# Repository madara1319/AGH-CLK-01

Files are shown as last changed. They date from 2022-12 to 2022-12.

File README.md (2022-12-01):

# AGH-CLK-01

Project of embedded wristwatch module powered by li-pol cell realised for University course Design-Laboratory
## Project assumptions
The main goal is to make self-contained embedded wristwatch module that could be used with dedicated wrist as a complete wristwatch. That device will have his own supply made by li-pol cell with dedicated hardware driver. As a display will be used full color LCD screen module with 240x240px and ST7789 driver. Device will be controlled by microprocessor STM32 (particular type will be pick in time) that would be placed on a dedicated printed circuit board “AGH-CLK-01” with the rest of peripherals. Everything should be assembled as a ready-to-use device.

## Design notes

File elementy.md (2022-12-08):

# Elementy smd do zakupienia

Do ustalenia w tym tygodniu co zakupujemy  

## N-Mosfet Conteo_pro  
[N-Mosfet](https://allegro.pl/oferta/irlml2060-60v-1-2a-n-mosfet-1-25w-sot-23-e1903-7875509949) 
https://allegro.pl/oferta/tranzystor-lge2300-n-mosfet-4a-20v-sot23-x10szt-8729061588 **(MM) electroniksc**
## P-Mosfet Elektroniksc  
[P-Mosfet](https://allegro.pl/oferta/irlml6402-sot23-p-channel-si2301-kpl-10szt-12848211828)  **(MM) ok**
## Kwarc Elektoniksc 
[Rezonator kwarcowy](https://allegro.pl/oferta/kwarc-32-768khz-smd-abs07-32-768khz-t-12-5pf-x2szt-12064929900)  **(MM) ok, ale w komplecie są 2 szt, więc wystarczą 2 komplety**

Kwarc inna firma  
Wymiar czestotliwosc okej i 4 piny  
[Rezonator kwarcowy](https://allegro.pl/oferta/rezonator-kwarcowy-smd-32-768khz-ndk-1szt-a529-6692482864)  **(MM) Nie ma sensu brać z innej firmy skoro mamy tamten**
## Gniazdo usb Conteo_pro 
[Gniazdo usb b](https://allegro.pl/oferta/mx-105017-0001-gniazdo-usb-b-micro-smt-5pin-12054224486) 
https://allegro.pl/oferta/gniazdo-micro-usb-5pin-pcb-10118194-0001lf-c-x2szt-9531914757 **(MM) gniazdo z electrosc**
## Modul do ladowarki Elektroniksc
[tp4056 do ladowarki lipo](https://allegro.pl/oferta/m5137-ladowarka-akumulatorow-li-ion-to4056-8863674707) Tu od elektronicsc z allegro co mosfet jeden wczesniej link ale trzeba by odlutowywac   
[tp4056 do ladowarki lipo](https://allegro.pl/oferta/tp4054-42-kontroler-ladowania-li-lon-sot23-5-7953080285) Tez od Elektroniksc ale to tp4054 i byloby bez odlutowywania  **(MM) Bardzo dobry pomysł**

## Stabilizator napiecia Conteo_pro
[stabilizator napięcia](https://allegro.pl/oferta/spx5205m5l3-3tr-stabilizator-napiecia-ldo-3-3v-12409161294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) **(MM) ok**
https://allegro.pl/oferta/stabilizator-ap2121n-3-3-ef8-sot23-3-3-3v-x4szt-9440621435 **(MM) jednak lepiej ten**

## Bufor inna firma
[Bufor](https://allegro.pl/oferta/sn74auc2g34dbvr-x4szt-12473535404) Bufor inny niz SN74AUC2G34DBVR ale podobny do 74AUC2G34 tylko nie jest ani od elektronicsc ani conteo_pro  
[Bufor](https://allegro.pl/oferta/nc7wz16p6x-smd-s-c-88-dual-buffer-9958671515)Inny bufor ale dual Buffer na CMOS [karta katalogowa](https://www.mouser.com/datasheet/2/308/NC7WZ16-1301496.pdf)  
[Bufor ale jakis inny ale od elektroniksc](https://allegro.pl/oferta/74lvc1g125gw-bufor-tssop5-x5szt-12080132627) nie wiem czy taki by byl bo nie dual buffer [karta katalogowa](https://www.mouser.pl/datasheet/2/916/74LVC1G125-1512149.pdf)  **(MM) ten będzie najtańszy**

[Bufor ale tez inny ale od conteo_pro](https://allegro.pl/oferta/m74vhc1gt125df2g-cyfrowy-3-stanowy-bufor-sc88a-11849828081) tez moze nie pasowac 3stanowy [karta katalogowa](https://www.mouser.com/datasheet/2/308/MC74VHC1GT125-D-78788.pdf)  
## Przycisk Elektroniksc
[Przycisk](https://allegro.pl/oferta/int1188f15a-mikroprzycisk-3-1x3-1-1-5mm-smd-7300457422)
Przycisk inny ale moze by był?  **(MM) hmm... powinien być raczej boczny a nie z góry Conteno ma w ofercie taki: https://allegro.pl/oferta/kss341glfs-mikroprzelacznik-tact-spst-no-smt-11768921473**  
**A tu jest nawet lepszy, bo w komplecie 10 sztuk https://allegro.pl/oferta/mikroprzycisk-4-7x1-9mm-3-5mm-smd-off-on-x10szt-10724789402**

## STM32 inna firma
[Zakladany stm32](https://allegrolokalnie.pl/oferta/mikrokontroler-stm32l051k6t6)  **(MM) Przy smarcie zakup 3 procków wystarczy, żeby mieć darmową dostawę, więc to jak najbardziej może być zakupione u kogoś innego**

[stm32 inny](https://allegro.pl/oferta/stm32g031j6m6-mikrokontroler-arm-32kb-64mhz-sop-8-11824556072) inny stm32 ale od Conteo_pro **(MM) Zdecydowanie zbyt mało pinów xD**

## Connector_wire_soldier_wire  
Tu do konca nie wiem jaki to drut ma byc  **(MM) aaa... rzeczywiście element THT. Chodziło mi tutaj o NTC 10k do kontroli temperatury baterii https://allegro.pl/oferta/termistor-ntc110-10k-1-3435k-pomiarowy-x5szt-12795393180 natomiast jeśli zdecydujemy się na ten alternatywny kontroler ładowania baterii to tam nie ma pomiaru temperatury i wtedy NTC też nie potrzebujemy**

## Cena za stmy
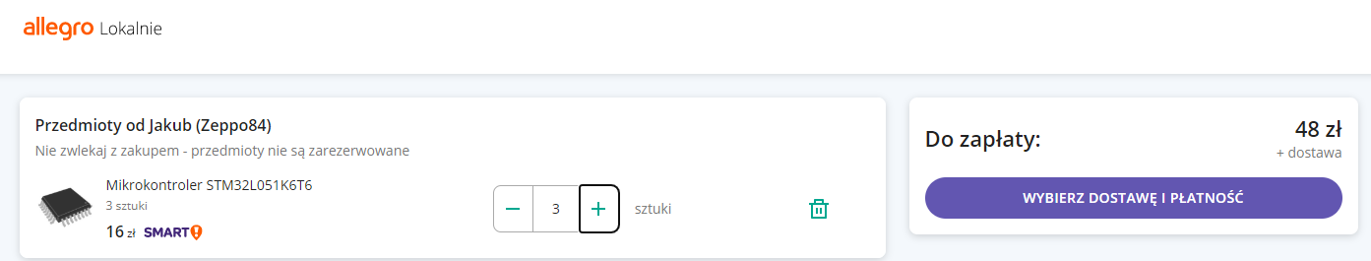
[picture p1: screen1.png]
Cena za stmy

## Cena za pozostale elementy
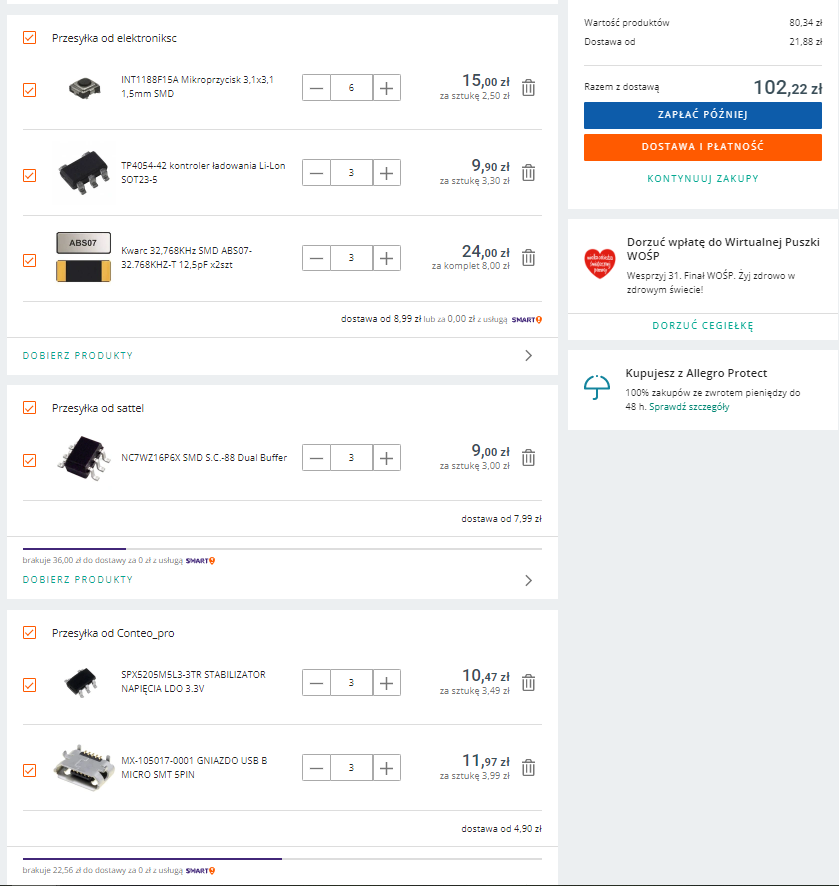
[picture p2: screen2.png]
Cena za pozostale elementy


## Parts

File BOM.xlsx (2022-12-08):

Ref | Qnty | Value | Cmp name | Footprint | Description
C1, C2, C3, | 3 | 100n | C | Capacitor_SMD:C_0603_1608Metric_Pad1.08x0.95mm_HandSolder | Unpolarized capacitor
C4, | 1 | 20pF | C | Capacitor_SMD:C_0603_1608Metric_Pad1.08x0.95mm_HandSolder | Unpolarized capacitor
C5, | 1 | 27pF | C | Capacitor_SMD:C_0603_1608Metric_Pad1.08x0.95mm_HandSolder | Unpolarized capacitor
C6, C7, C8, | 3 | 1u | C | Capacitor_SMD:C_0805_2012Metric_Pad1.18x1.45mm_HandSolder | Unpolarized capacitor
C9, C11, | 2 | 10uF | C | Capacitor_SMD:C_1206_3216Metric_Pad1.33x1.80mm_HandSolder | Unpolarized capacitor
C10, C12, | 2 | 100nF | C | Capacitor_SMD:C_0603_1608Metric_Pad1.08x0.95mm_HandSolder | Unpolarized capacitor
D1, D2, | 2 | BAT54S | BAT54S | Package_TO_SOT_SMD:SOT-23 | schottky barrier diode
J1, | 1 | Conn_01x06_Male | Conn_01x06_Male | Connector_PinHeader_2.54mm:PinHeader_1x06_P2.54mm_Vertical | Generic connector, single row, 01x06, script generated (kicad-library-utils/schlib/autogen/connector/)
J2, | 1 | USB_B_Micro | USB_B_Micro | Connector_USB:USB_Micro-B_Amphenol_10104110_Horizontal | USB Micro Type B connector
J3, | 1 | Conn_01x03_Male | Conn_01x03_Male | Connector_PinHeader_2.54mm:PinHeader_1x03_P2.54mm_Vertical | Generic connector, single row, 01x03, script generated (kicad-library-utils/schlib/autogen/connector/)
J4, | 1 | Conn_01x12 | Conn_01x12 | Connector:Flex_Tape_12x0.635 | Generic connector, single row, 01x12, script generated (kicad-library-utils/schlib/autogen/connector/)
J5, | 1 | Conn_01x02_Male | Conn_01x02_Male | Connector_PinHeader_2.54mm:PinHeader_1x02_P2.54mm_Vertical | Generic connector, single row, 01x02, script generated (kicad-library-utils/schlib/autogen/connector/)
NTC1, | 1 | R | R | Connector_Wire:SolderWire-0.5sqmm_1x02_P4.6mm_D0.9mm_OD2.1mm | Resistor
Q1, | 1 | IRLML2060 | IRLML2060 | Package_TO_SOT_SMD:SOT-23 | 1.2A Id, 60V Vds, 480mOhm Rds, N-Channel HEXFET Power MOSFET, SOT-23
Q2, | 1 | IRLML6402 | IRLML6402 | Package_TO_SOT_SMD:SOT-23 | -3.7A Id, -20V Vds, 65mOhm Rds, P-Channel HEXFET Power MOSFET, SOT-23
Q3, | 1 | BC817 | BC817 | Package_TO_SOT_SMD:SOT-23 | 0.8A Ic, 45V Vce, NPN Transistor, SOT-23
R1, R3, R4, | 3 | 100R | R | Resistor_SMD:R_0603_1608Metric_Pad0.98x0.95mm_HandSolder | Resistor
R2, R6, | 2 | 100k | R | Resistor_SMD:R_0603_1608Metric_Pad0.98x0.95mm_HandSolder | Resistor
R5, R7, R9, R14, R15, | 5 | 10k | R | Resistor_SMD:R_0603_1608Metric_Pad0.98x0.95mm_HandSolder | Resistor
R8, | 1 | 1k | R | Resistor_SMD:R_0603_1608Metric_Pad0.98x0.95mm_HandSolder | Resistor
R10, | 1 | 10R | R | Resistor_SMD:R_0603_1608Metric_Pad0.98x0.95mm_HandSolder | Resistor
R11, R12, | 2 | R | R | Resistor_SMD:R_0603_1608Metric_Pad0.98x0.95mm_HandSolder | Resistor
R13, | 1 | 2,4k | R | Resistor_SMD:R_0603_1608Metric_Pad0.98x0.95mm_HandSolder | Resistor
SW1, SW2, | 2 | SW_Push | SW_Push | Button_Switch_SMD:SW_SPST_B3U-3000P-B | Push button switch, generic, two pins
U1, | 1 | STM32L051K6Tx | STM32L051K6Tx | Package_QFP:LQFP-32_7x7mm_P0.8mm | ARM Cortex-M0+ MCU, 32KB flash, 8KB RAM, 32MHz, 1.65-3.6V, 25 GPIO, LQFP-32
U2, | 1 | MIC5353-3.3YMT | MIC5353-3.3YMT | Package_DFN_QFN:MLF-6-1EP_1.6x1.6mm_P0.5mm_EP0.5x1.26mm | High-performance, single-output, ultra-low LDO regulator
U3, | 1 | 74AUC2G34 | 74AUC2G34 | Package_TO_SOT_SMD:SOT-23-6_Handsoldering | Dual Buffer, Low-Voltage CMOS
U4, | 1 | TP4056 | TP4056 | Package_SO:HSOP-8-1EP_3.9x4.9mm_P1.27mm_EP2.41x3.1mm
Y1, | 1 | Crystal_GND24 | Crystal_GND23 | Crystal:Crystal_SMD_Abracon_ABS25-4Pin_8.0x3.8mm | Four pin crystal, GND on pins 2 and 3

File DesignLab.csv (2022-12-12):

Source: | D:\Projekty\AGH-CLK-01\Hardware\AGH-CLK-01\DesignLab.kicad_sch
Date: | 12/12/2022 12:11:36 PM
Tool: | Eeschema (6.0.9)
Generator: | D:\Programy\Zainstalowane\KiCad\6.0\bin\scripting\plugins/bom_csv_grouped_by_value_with_fp.py
Component Count: | 49
Ref | Qnty | Value | Cmp name | Footprint | Description | Vendor
C1, C2, C3, | 3 | 100n | C | Capacitor_SMD:C_0603_1608Metric_Pad1.08x0.95mm_HandSolder | Unpolarized capacitor
C4, | 1 | 20pF | C | Capacitor_SMD:C_0603_1608Metric_Pad1.08x0.95mm_HandSolder | Unpolarized capacitor
C5, | 1 | 27pF | C | Capacitor_SMD:C_0603_1608Metric_Pad1.08x0.95mm_HandSolder | Unpolarized capacitor
C6, C8, | 2 | 1u | C | Capacitor_SMD:C_0805_2012Metric_Pad1.18x1.45mm_HandSolder | Unpolarized capacitor
C7, C9, C10, C12, C13, | 5 | 100n | C | Capacitor_SMD:C_0805_2012Metric_Pad1.18x1.45mm_HandSolder | Unpolarized capacitor
C11, | 1 | 1u | C | Capacitor_SMD:C_1206_3216Metric_Pad1.33x1.80mm_HandSolder | Unpolarized capacitor
D1, D2, | 2 | BAT54S | BAT54S | Package_TO_SOT_SMD:SOT-23 | schottky barrier diode
H1, H2, H3, H4, | 4 | MountingHole | MountingHole | MountingHole:MountingHole_2.2mm_M2_ISO7380 | Mounting Hole without connection
J1, | 1 | Conn_01x06_Male | Conn_01x06_Male | Connector_PinHeader_2.54mm:PinHeader_2x03_P2.54mm_Vertical | Generic connector, single row, 01x06, script generated (kicad-library-utils/schlib/autogen/connector/)
J2, | 1 | USB_B_Micro | USB_B_Micro | Connector_USB:USB_Micro-B_Amphenol_10118194_Horizontal | USB Micro Type B connector
J3, | 1 | Conn_01x03_Male | Conn_01x03_Male | Connector_PinHeader_2.54mm:PinHeader_1x03_P2.54mm_Vertical | Generic connector, single row, 01x03, script generated (kicad-library-utils/schlib/autogen/connector/)
J4, | 1 | Conn_01x12 | Conn_01x12 | Connector:Flex_Tape_12x0.635 | Generic connector, single row, 01x12, script generated (kicad-library-utils/schlib/autogen/connector/)
J5, | 1 | Conn_01x02_Male | Conn_01x02_Male | Connector_PinHeader_2.54mm:PinHeader_1x02_P2.54mm_Vertical | Generic connector, single row, 01x02, script generated (kicad-library-utils/schlib/autogen/connector/)
Q1, | 1 | IRLML2060 | IRLML2060 | Package_TO_SOT_SMD:SOT-23 | 1.2A Id, 60V Vds, 480mOhm Rds, N-Channel HEXFET Power MOSFET, SOT-23
Q2, | 1 | IRLML6402 | IRLML6402 | Package_TO_SOT_SMD:SOT-23 | -3.7A Id, -20V Vds, 65mOhm Rds, P-Channel HEXFET Power MOSFET, SOT-23
Q3, | 1 | BC817 | BC817 | Package_TO_SOT_SMD:SOT-23 | 0.8A Ic, 45V Vce, NPN Transistor, SOT-23
R1, R2, R3, | 3 | 100R | R | Resistor_SMD:R_0603_1608Metric_Pad0.98x0.95mm_HandSolder | Resistor
R4, R7, R9, R12, R14, | 5 | 10k | R | Resistor_SMD:R_0603_1608Metric_Pad0.98x0.95mm_HandSolder | Resistor
R5, R6, | 2 | 100k | R | Resistor_SMD:R_0603_1608Metric_Pad0.98x0.95mm_HandSolder | Resistor
R8, R11, R13, | 3 | 1k | R | Resistor_SMD:R_0603_1608Metric_Pad0.98x0.95mm_HandSolder | Resistor
R10, | 1 | 10R | R | Resistor_SMD:R_0603_1608Metric_Pad0.98x0.95mm_HandSolder | Resistor
SW1, SW2, | 2 | SW_Push | SW_Push | Button_Switch_SMD:SW_SPST_TSS02-035NT | Push button switch, generic, two pins
U1, | 1 | STM32L051K6Tx | STM32L051K6Tx | Package_QFP:LQFP-32_7x7mm_P0.8mm | ARM Cortex-M0+ MCU, 32KB flash, 8KB RAM, 32MHz, 1.65-3.6V, 25 GPIO, LQFP-32
U2, | 1 | AP2127N-3.3 | AP2127N-3.3 | Package_TO_SOT_SMD:SOT-23 | 300mA low dropout linear regulator, shutdown pin, 2.5V-6V input voltage, 3.3V fixed positive output, SOT-23 package
U3, U4, | 2 | 74LVC1G125 | 74LVC1G125 | Package_TO_SOT_SMD:SOT-23-5_HandSoldering | Single Buffer Gate Tri-State, Low-Voltage CMOS
U5, | 1 | TP4054-42 | TP4054-42 | Package_TO_SOT_SMD:SOT-23-5_HandSoldering
Y1, | 1 | Crystal | Crystal | Crystal:Crystal_SMD_3215-2Pin_3.2x1.5mm | Two pin crystal

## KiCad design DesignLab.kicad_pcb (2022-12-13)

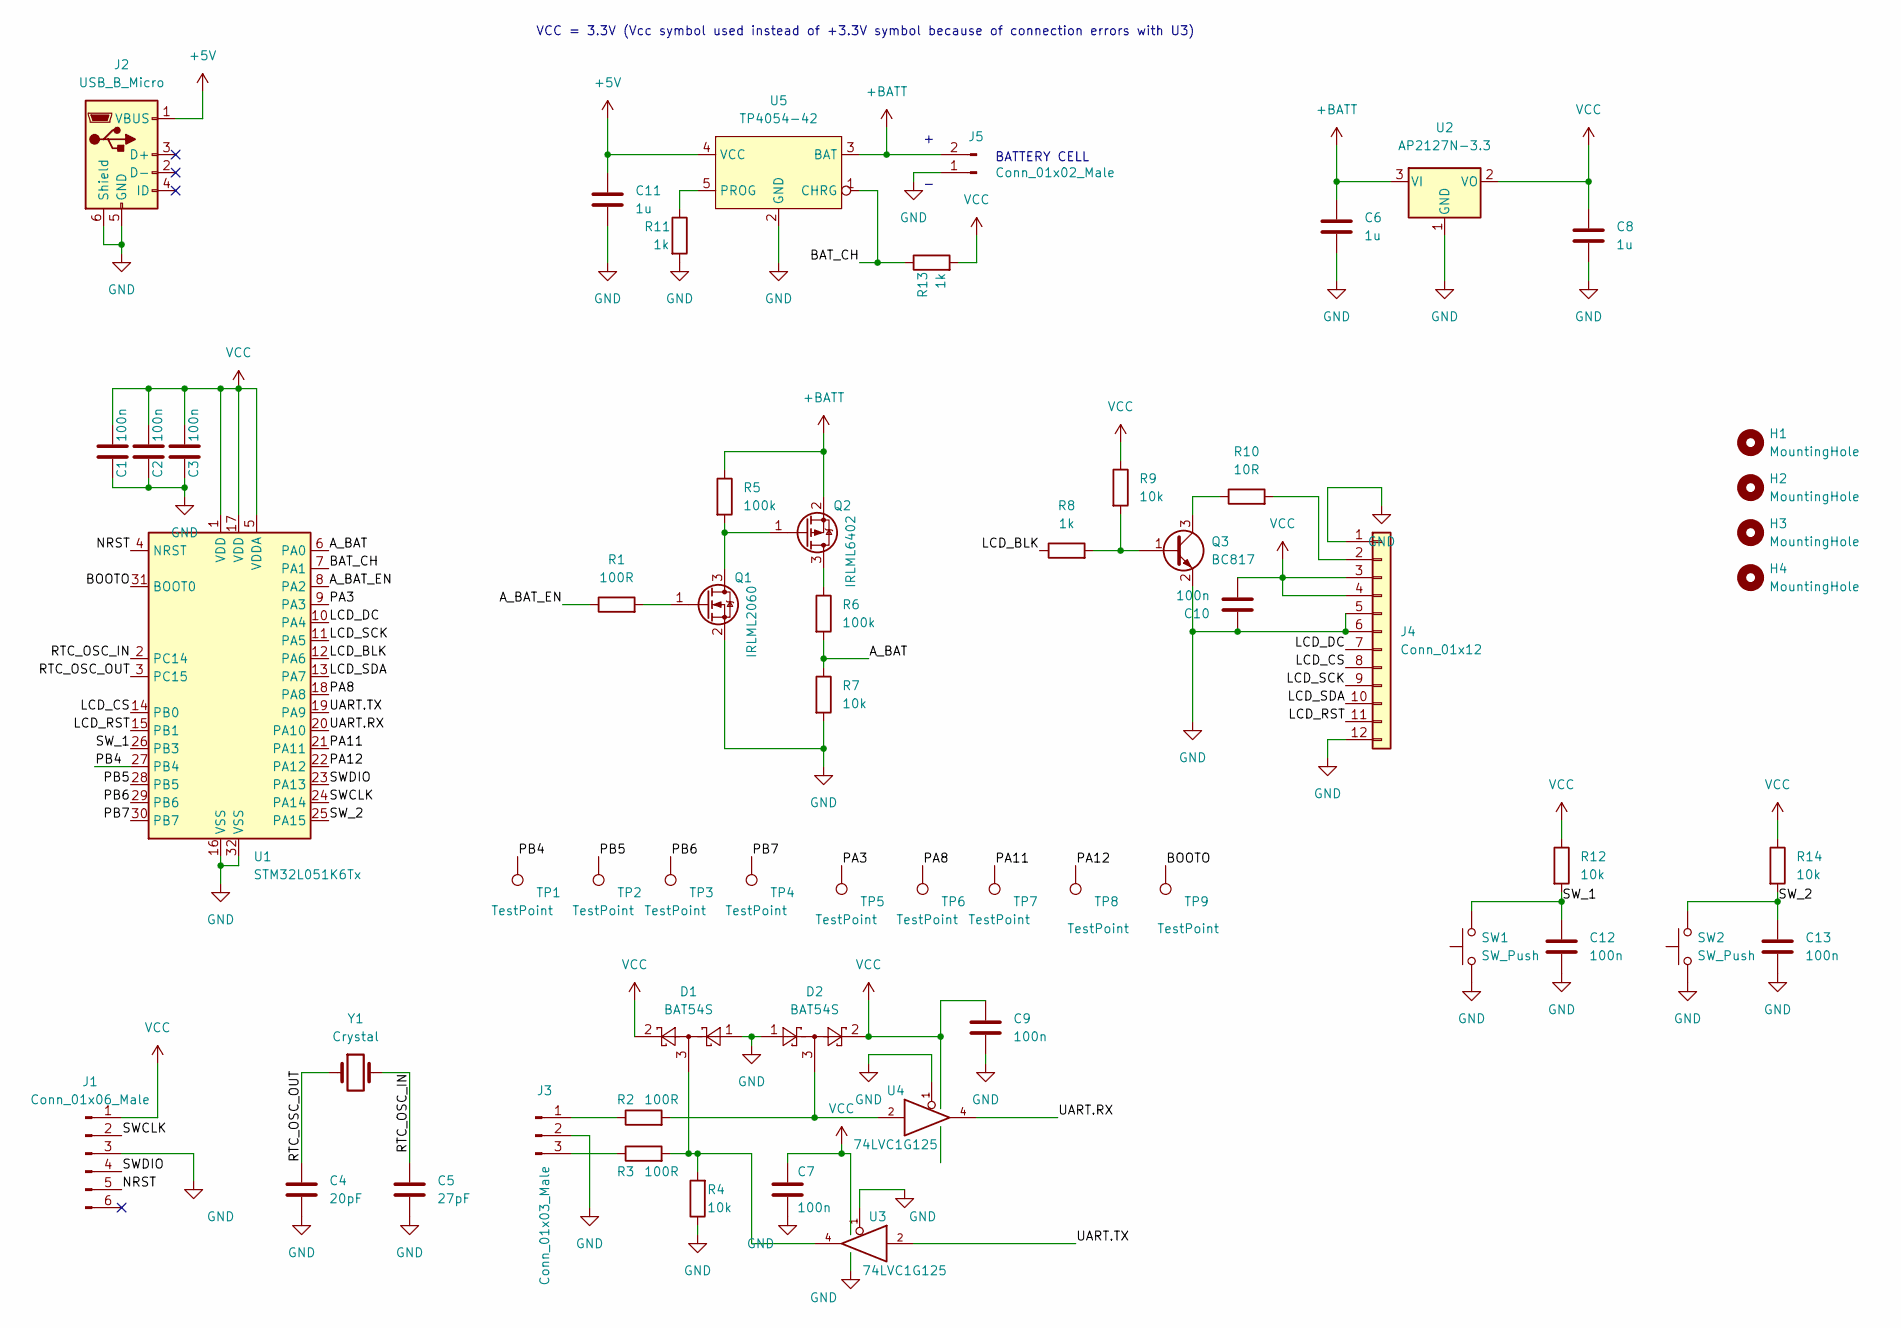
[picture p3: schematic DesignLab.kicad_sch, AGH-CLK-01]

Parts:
C1, C2, C3: 100n; C_0603_1608Metric_Pad1.08x0.95mm_HandSolder
C4: 20pF; C_0603_1608Metric_Pad1.08x0.95mm_HandSolder
C5: 27pF; C_0603_1608Metric_Pad1.08x0.95mm_HandSolder
C6, C8: 1u; C_0805_2012Metric_Pad1.18x1.45mm_HandSolder
C7, C9, C10, C12, C13: 100n; C_0805_2012Metric_Pad1.18x1.45mm_HandSolder
C11: 1u; C_1206_3216Metric_Pad1.33x1.80mm_HandSolder
D1, D2: BAT54S; SOT-23
H1, H2, H3, H4: MountingHole; MountingHole_2.2mm_M2_ISO7380
J1: Conn_01x06_Male; PinHeader_2x03_P2.54mm_Vertical
J2: USB_B_Micro; USB_Micro-B_Amphenol_10118194_Horizontal
J3: Conn_01x03_Male; PinHeader_1x03_P2.54mm_Vertical
J4: Conn_01x12; Flex_Tape_12x0.635
J5: Conn_01x02_Male; PinHeader_1x02_P2.54mm_Vertical
Q1: IRLML2060; SOT-23
Q2: IRLML6402; SOT-23
Q3: BC817; SOT-23
R1, R2, R3: 100R; R_0603_1608Metric_Pad0.98x0.95mm_HandSolder
R4, R7, R9, R12, R14: 10k; R_0603_1608Metric_Pad0.98x0.95mm_HandSolder
R5, R6: 100k; R_0603_1608Metric_Pad0.98x0.95mm_HandSolder
R8, R11, R13: 1k; R_0603_1608Metric_Pad0.98x0.95mm_HandSolder
R10: 10R; R_0603_1608Metric_Pad0.98x0.95mm_HandSolder
SW1, SW2: SW_Push; SW_SPST_TSS02-035NT
TP1, TP2, TP3, TP4, TP5, TP6, TP7, TP8, TP9: TestPoint; TestPoint_Pad_1.5x1.5mm
U1: STM32L051K6Tx; LQFP-32_7x7mm_P0.8mm
U2: AP2127N-3.3; SOT-23
U3, U4: 74LVC1G125; SOT-23-5_HandSoldering
U5: TP4054-42; SOT-23-5_HandSoldering
Y1: Crystal; Crystal_SMD_3215-2Pin_3.2x1.5mm

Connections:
+5V: C11.1, J2.1 (VBUS), U5.4 (VCC)
+BATT: C6.1, J5.2, Q2.2 (S), R5.1, U2.3 (VI), U5.3 (BAT)
/A_BAT: R6.2, R7.1, U1.6 (PA0)
/A_BAT_EN: R1.1, U1.8 (PA2)
/BAT_CH: R13.1, U1.7 (PA1), U5.1 (CHRG)
/BOOTO: TP9.1, U1.31 (BOOT0)
/LCD_BLK: R8.1, U1.12 (PA6)
/LCD_CS: J4.8, U1.14 (PB0)
/LCD_DC: J4.7, U1.10 (PA4)
/LCD_RST: J4.11, U1.15 (PB1)
/LCD_SCK: J4.9, U1.11 (PA5)
/LCD_SDA: J4.10, U1.13 (PA7)
/NRST: J1.5, U1.4 (NRST)
/PA3: TP5.1, U1.9 (PA3)
/PA8: TP6.1, U1.18 (PA8)
/PA11: TP7.1, U1.21 (PA11)
/PA12: TP8.1, U1.22 (PA12)
/PB4: TP1.1, U1.27 (PB4)
/PB5: TP2.1, U1.28 (PB5)
/PB6: TP3.1, U1.29 (PB6)
/PB7: TP4.1, U1.30 (PB7)
/RTC_OSC_IN: C5.1, U1.2 (PC14), Y1.2
/RTC_OSC_OUT: C4.1, U1.3 (PC15), Y1.1
/SWCLK: J1.2, U1.24 (PA14)
/SWDIO: J1.4, U1.23 (PA13)
/SW_1: C12.1, R12.2, SW1.2, U1.26 (PB3)
/SW_2: C13.1, R14.2, SW2.2, U1.25 (PA15)
/UART.RX: U1.20 (PA10), U4.4
/UART.TX: U1.19 (PA9), U3.2
GND: C1.2, C2.2, C3.2, C4.2, C5.2, C6.2, C7.2, C8.2, C9.2, C10.1, C11.2, C12.2, C13.2, D1.1, D2.1, J1.3, J2.5 (GND), J2.6 (Shield), J3.2, J4.1, J4.5, J4.6, J4.12, J5.1, Q1.2 (S), Q3.2 (E), R4.1, R7.2, R11.2, SW1.1, SW2.1, U1.16 (VSS), U1.32 (VSS), U2.1 (GND), U3.1, U3.3 (GND), U4.1, U4.3 (GND), U5.2 (GND)
unnamed: D1.3, R3.2, R4.2, U3.4
unnamed: D2.3, R2.2, U4.2
unnamed: J3.1, R2.1
unnamed: J3.3, R3.1
unnamed: J4.2, R10.2
unnamed: Q1.1 (G), R1.2
unnamed: Q1.3 (D), Q2.1 (G), R5.2
unnamed: Q2.3 (D), R6.1
unnamed: Q3.1 (B), R8.2, R9.2
unnamed: Q3.3 (C), R10.1
unnamed: R11.1, U5.5 (PROG)
VCC: C1.1, C2.1, C3.1, C7.1, C8.1, C9.1, C10.2, D1.2, D2.2, J1.1, J4.3, J4.4, R9.1, R12.1, R13.2, R14.1, U1.1 (VDD), U1.5 (VDDA), U1.17 (VDD), U2.2 (VO), U3.5 (VCC), U4.5 (VCC)

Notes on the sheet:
VCC = 3.3V (Vcc symbol used instead of +3.3V symbol because of connection errors with U3)
BATTERY CELL

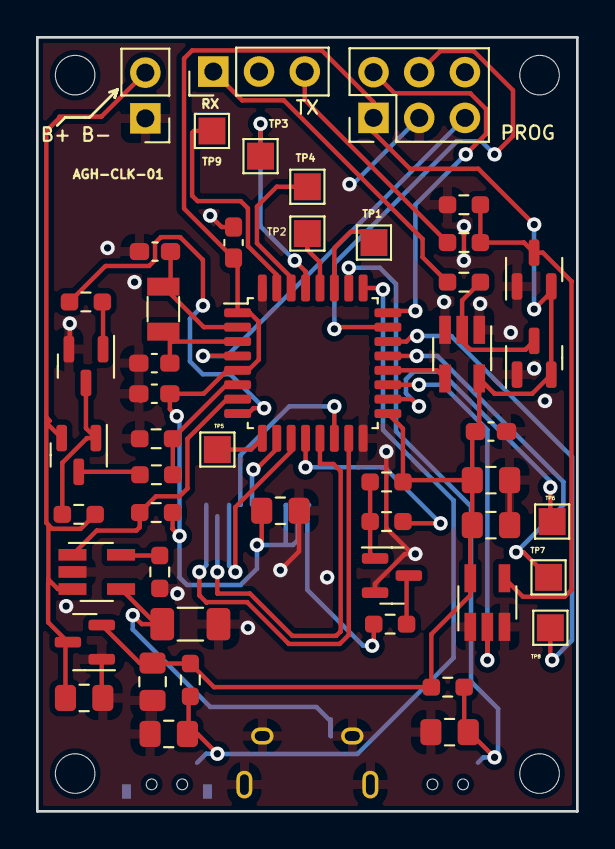
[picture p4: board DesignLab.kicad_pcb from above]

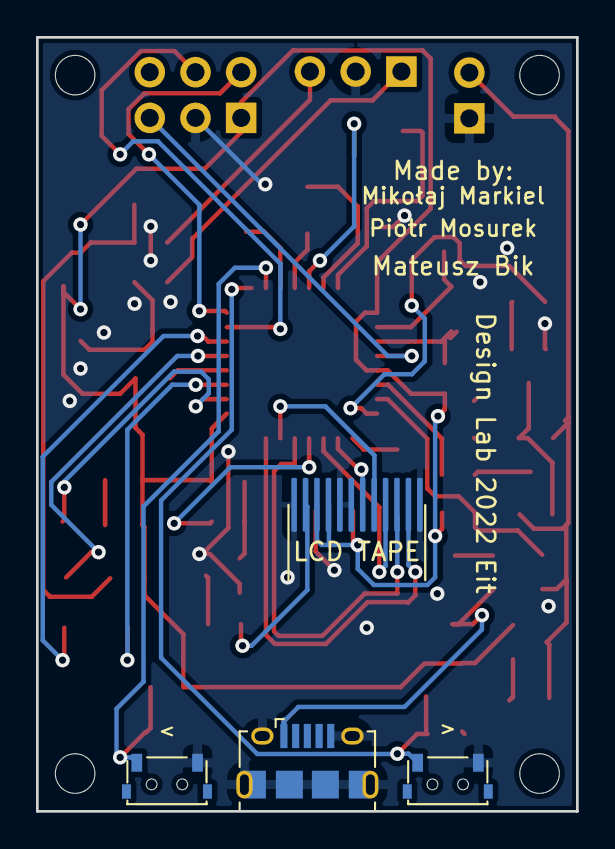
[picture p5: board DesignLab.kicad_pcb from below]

Board: 2 copper layers, 30.0 x 43.0 mm, 58 parts (4 on the bottom side), 42 nets.

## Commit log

2022-12-06 v0.2 06.12.2022 MM
    Completed schematic file
    [DesignLab.csv, DesignLab.kicad_pcb, DesignLab.kicad_sch]
2022-12-06 v0.3
    Updated BOM
    [DesignLab.csv]
2022-12-08 v0.4 - MM - updated schematic
    [BOM.xlsx, DesignLab.csv, DesignLab.kicad_pcb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]
2022-12-08 v0.5 updated schematic
    changed quartz symbol, changed switch footprints, added folder lib/footprints with necessary contents
    [DesignLab.csv, DesignLab.kicad_sch]
2022-12-09 v0.6 updated schematic + footprints
    [DesignLab.kicad_sch]
2022-12-09 zmiany 9.12 15:00
    brak c11-c13 w schemacie pcb, próby autoroutingu
    [DesignLab.kicad_pcb]
2022-12-09 edit
    edit
    [DesignLab.kicad_pcb]
2022-12-10 c
    zmiana w c11 i c12 jednostki farad dalsze problemy z c10-c13 przy dodaniu na pcb
    [DesignLab.kicad_sch]
2022-12-12 v0.8 updated layout
    [DesignLab.csv, DesignLab.kicad_pcb, DesignLab.kicad_sch]
2022-12-12 v0.9 updated schematic
    [DesignLab.kicad_pcb]
2022-12-12 layout PCB draw 0.1version
    prawie skończone
    [DesignLab.kicad_pcb, DesignLab.kicad_sch]
2022-12-13 Layout PCB v0.2
    almost finish layout pcb without error
    [DesignLab.kicad_pcb]
